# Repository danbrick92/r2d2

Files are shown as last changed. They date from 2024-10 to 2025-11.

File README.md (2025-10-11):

# R2D2
Create yourself an R2D2 robot! 

# Description
This robot, assuming all the electronic components are added, will have the ability to not only be remotely controlled, but has imaging, sound, and autonomous navigation. 

# Current State
Currently, this project is very much a WIP! I will update the README with a working YouTube video to showcase it's ability as a I go.

# Getting Started
There is a lot to setup with this. Considering this project includes electronics, 3d printing, robotics, software engineering, AI and more, this is both an expensive and complex project. 

## Essentials
To get started, you will need:
 - A 3d printer w/ plenty of filament
 - A soldering iron
 - Good working knowledge of: 
    - Electronics
    - 3d Printing
    - Linux
    - Docker
    - Robotics Operating System 2 (ROS2)
    - Python
    - C++
    - Machine Learning and AI

## Parts
You will need the following parts to mimic this design exactly. It is not cheap. 

### Computing Core
1) Raspberry Pi 5 8GB: https://www.canakit.com/raspberry-pi-5-8gb.html 
2) Raspberry Pi AI Kit with Extended Turbine Case, Fan, and Mega Heat Sink: https://www.canakit.com/raspberry-pi-ai-kit-with-case.html
    - You can also order these parts separate. 
    - The AI Kit is a Hailo 8L accelerator with up to 13 TOPS (Trillions of Operations Per Second) inferencing performance.
3) 512 GB MicroSD Card: https://www.amazon.com/dp/B09X7C2GBC
4) Arduino Uno: https://www.amazon.com/AEDIKO-Motor-Gearbox-Shaft-200RPM/dp/B099Z85573/ 

### Movement
1) TT Motor DC 3-6V Gearbox Motor Dual Shaft: https://www.amazon.com/AEDIKO-Motor-Gearbox-Shaft-200RPM/dp/B099Z85573/
2) Caster Wheels: https://www.amazon.com/dp/B0CZ9GNXSQ
3) Accelerometer/Gyroscope: https://www.amazon.com/dp/B00LP25V1A

### Power
1) 12V 5200mAh Battery: https://www.amazon.com/dp/B0C242DYT1
2) DC 9V 12V 24V to DC 5V 5A Buck Converter Module: https://www.amazon.com/UCTRONICS-Converter-Transformer-Voltage-Regulator/dp/B07XXWQ49N 
3) A USB C to USB A Cable: https://www.amazon.com/dp/B07DD5YHMH 
4) 22 awg Wires: https://www.amazon.com/dp/B07TX6BX47
5) Wire Strippers: https://www.amazon.com/dp/B073YG65N2  

### Imaging
1) USB Camera: https://www.amazon.com/Ximimark-Camera-Raspberry-Require-Drivers/dp/B07GWP2SGV/
2) LIDAR (TF Luna): https://www.amazon.com/gp/product/B088NVX2L7
3) LIDAR Cables: https://www.amazon.com/dp/B07PWZTC88 

## 3-D Prints

### R2D2

There are many good base models online. I found one (located in the credits section) and modified it to fit all the electronic components and screw together nicely.

I used white PETG for the feet, and white PLA for all other components. For the head and other details, I used 220 grit sandpaper and the following paints:
- Silver: Rust-Oleum Universal Titanium Silver Metallic
- Blue: Rust-Oleum Metallic Brilliant Metal Finish (Cobalt Blue)
- Gloss/Sealant: Rust-Oleum Gloss Clear Enamel

### Test Board

For me, it was helpful to have an easy test board before proceeding with the design of R2D2.

I created a circular plastic body with M3-sized holes and two expansion shafts to support multiple layers. For each layer, print:
- (1) roundBody 
- (2-3) shaftExpansion

On the top layer, you can print 
- (1) cameraLidarHolder, which allows the lidar and camera to mount to the top plate

You can also print cubeHolders as needed to secure your boards/equipment

You can access the stl prints in print/test/
I purchased these M3 screws from Amazon: https://www.amazon.com/dp/B0BMQFHDBH

This 3D print was very helpful to mount the motors to the bottom of the board: https://www.thingiverse.com/thing:1473508 

## Electronics
Here is the breadboard design for setting up this system:
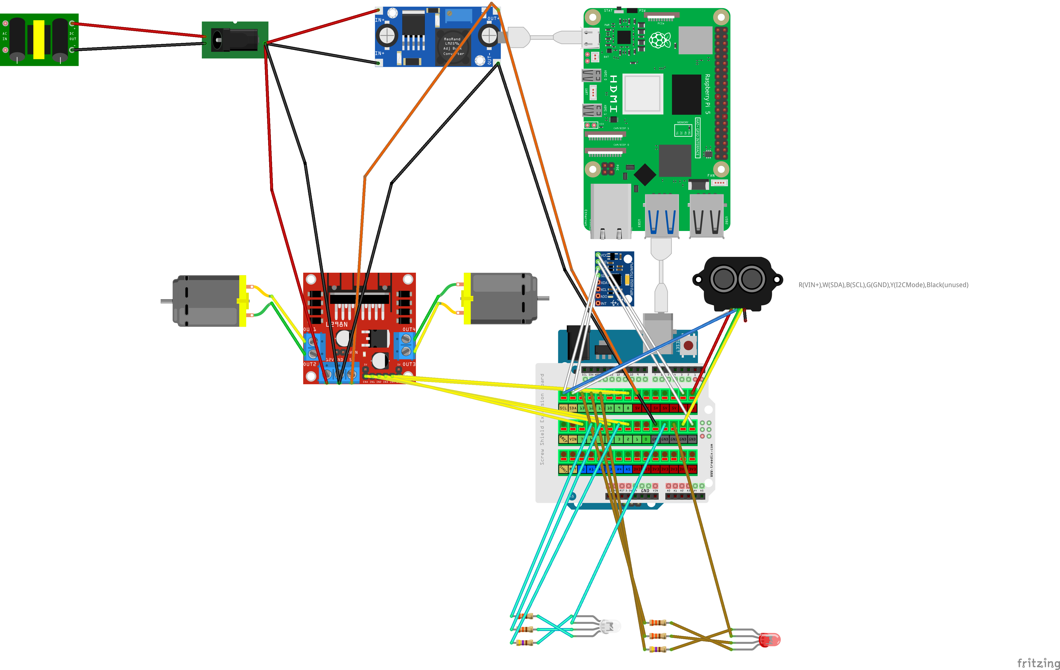
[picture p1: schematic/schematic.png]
The schematic
 

I've left the Fritzing project here and the subparts used in case anyone wants to alter the design.

# Installation
NOTE THAT THIS IS STILL VERY MUCH A WIP. 
1) Load up your Raspberry PI 5 with a 64-bit installation of Raspberry PI. The version I used was Raspberry PI OS 12.7 64-bit.
2) Once the PI is booted and ready, copy the contents of this repo into a directory you prefer.
3) Open a terminal up and cd to the src directory. 
4) Run ```sudo pi/install.sh``` - this will install Docker, ROS, and a number of other dependencies
5) Finally, you should be able to run ```sudo run.sh``` - this will run the robotics engine

# Running It
TBD

# Credits
## 3-D Printed Parts

### r2d2
This project is a remix of the R2D2 Alexa Echo Dot 3 Dock created by Gerrylum, licensed under CC BY-NC 4.0: https://www.printables.com/model/35415-screen-accurate-r2d2-alexa-echo-dot-3-dock

I modified the original design by scaling it up, making accomodations for electronic components, and screw holes.

Additional body detail parts were sourced from this remix.

### motorMount
Motor mount by b2vn on Thingiverse: https://www.thingiverse.com/thing:1473508
This 3D model was created by b2vn on Thingiverse and is licensed under the Creative Commons Attribution-ShareAlike (CC BY-SA) license.

### 28BYJ-48 Motor Welle Shaft Crankshaft Extension
https://www.thingiverse.com/thing:6189216/files

### 28BYJ-48 Mounting Bracket
https://www.thingiverse.com/thing:423357/files

## Sounds
Sounds downloaded from: https://www.101soundboards.com/boards/10634-r2-d2-sounds-star-wars

## Fritzing Parts
### bb-usb-cable
This part was created by vanepp on the Fritzing Forum.
The part is shared for public use as part of the open-source Fritzing community.
Original Source: https://forum.fritzing.org/t/usb-cable-in-breadboard-view/11697

### dc_motor_devre
This part was created by bminaa on the Fritzing website.
The part is shared for public use as part of the open-source Fritzing community.
Original Source: https://fritzing.org/projects/dc-motor

### generic-ac-power-supply
This part was created by vanepp on the Fritzing Forum.
The part is shared for public use as part of the open-source Fritzing community.
Original Source: https://forum.fritzing.org/t/i-need-a-power-supply/8471

### L298N DC motor driver
This part was created by codefls on the Fritzing Forum.
The part is shared for public use as part of the open-source Fritzing community.
Original Source: https://forum.fritzing.org/t/h-bridge-with-l298n-motor-driver/7711 

### MPU-6050 Board GY-521
This part was created by charlesrct on the Fritzing Website.
The part is shared for public use as part of the open-source Fritzing community.
Original Source: https://fritzing.org/projects/mpu-6050-board-gy-521-acelerometro-y-giroscopio 

### Raspberry-Pi5
This part was created by vanepp on the Fritzing Forum.
The part is shared for public use as part of the open-source Fritzing community.
Original Source: https://forum.fritzing.org/t/looking-for-raspberry-pi-5-fritzing-part/21511

### tfluna-lidar
This part was created by vanepp on the Fritzing Forum.
The part is shared for public use as part of the open-source Fritzing community.
Original Source: https://forum.fritzing.org/t/tf-luna-8m-low-cost-distance-sensor/16499

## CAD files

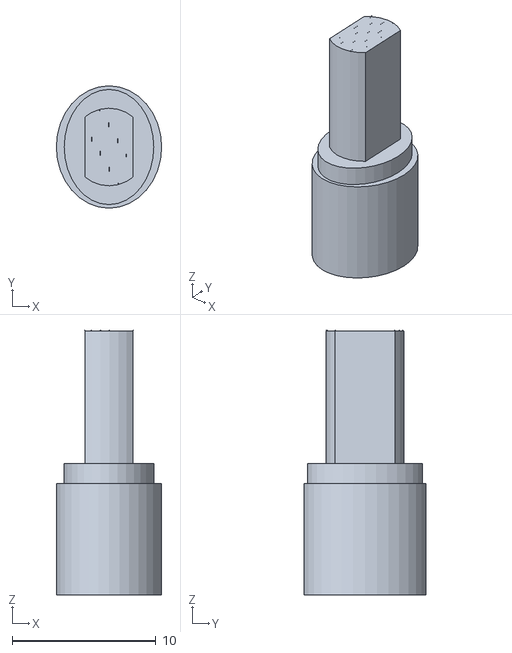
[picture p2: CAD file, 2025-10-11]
print/real/ref/28byj-48-MotorwelleShaft_ungefahr.stl
7.34 x 8.52 x 18.5

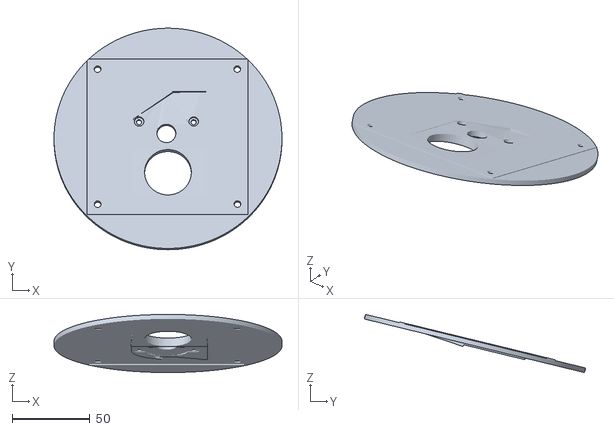
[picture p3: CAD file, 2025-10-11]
print/real/v1/body_susan_mount.stl
146.3 x 142.1 x 37.3

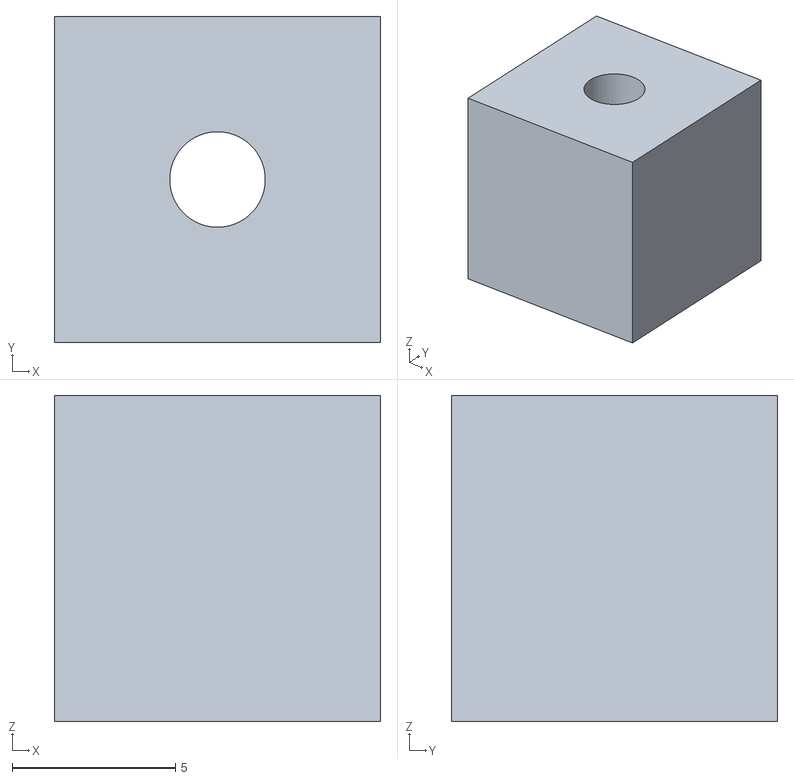
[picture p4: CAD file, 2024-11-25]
print/test/cubeHolder.stl
10.0 x 10.0 x 10.0

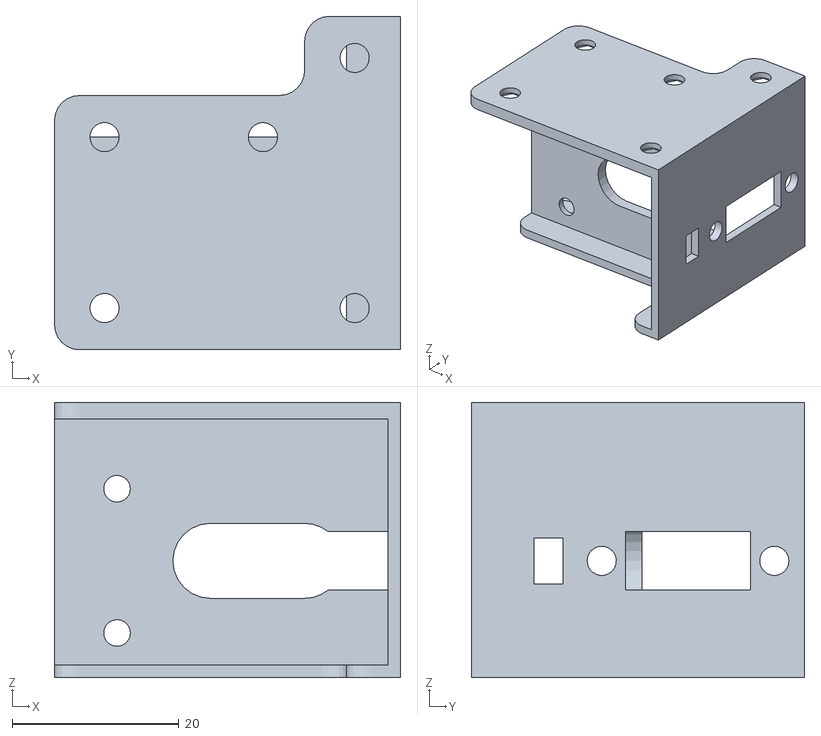
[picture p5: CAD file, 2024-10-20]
print/test/motorMount/files/motorMount.stl
41.5 x 40.0 x 33.0

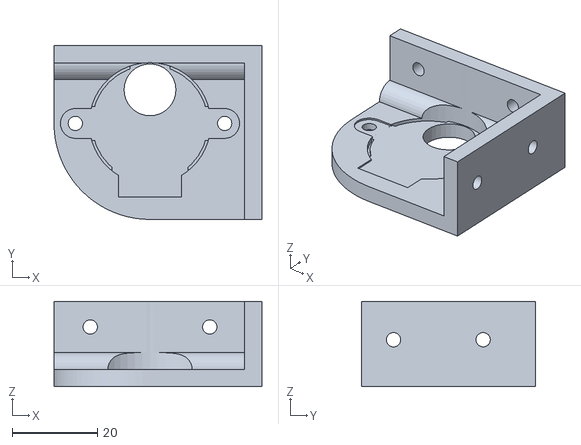
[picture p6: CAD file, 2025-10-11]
print/real/ref/Bracket_28BYJ-48_v3.stl
48.8 x 40.8 x 20.0

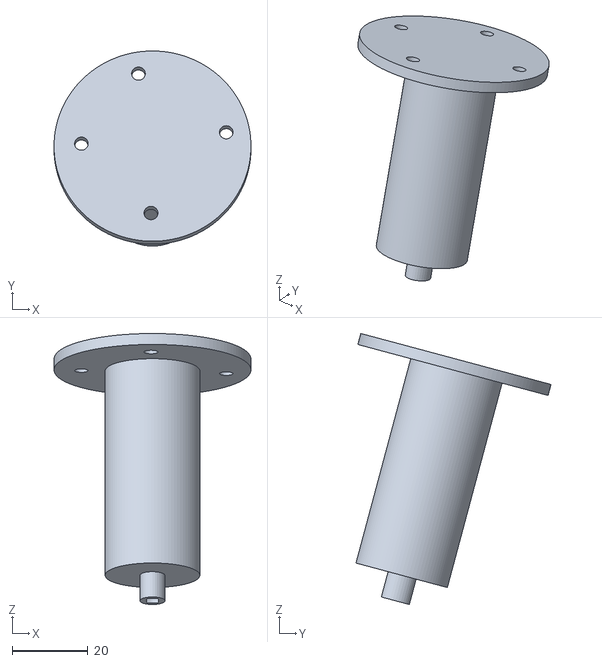
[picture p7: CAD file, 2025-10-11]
print/real/v1/motor_shaft.stl
52.0 x 51.5 x 71.5

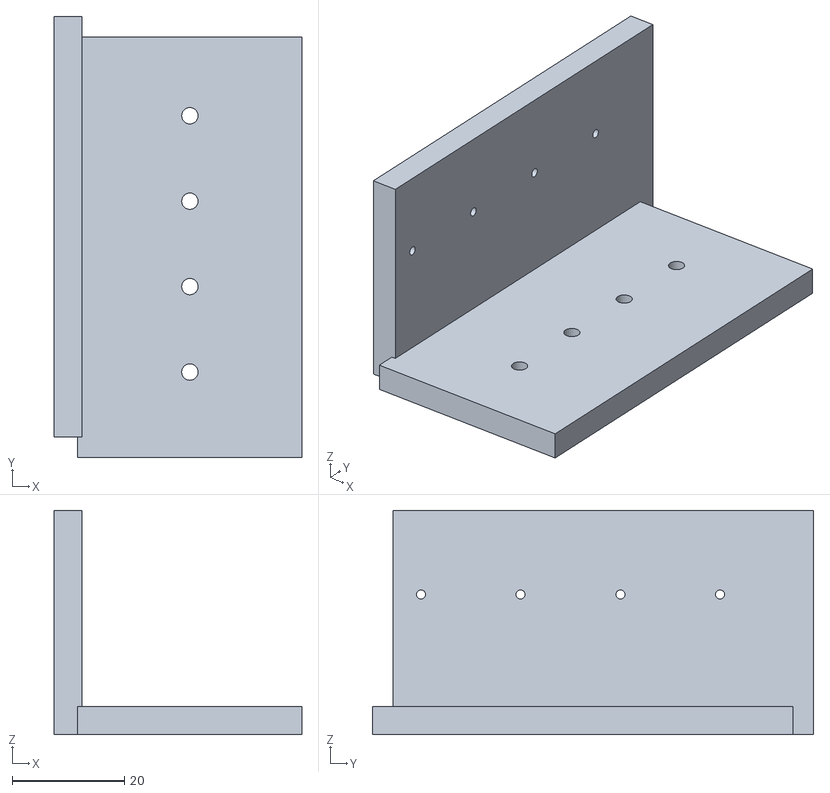
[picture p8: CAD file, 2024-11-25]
print/test/cameraLidarHolder.stl
44.2 x 78.7 x 40.0

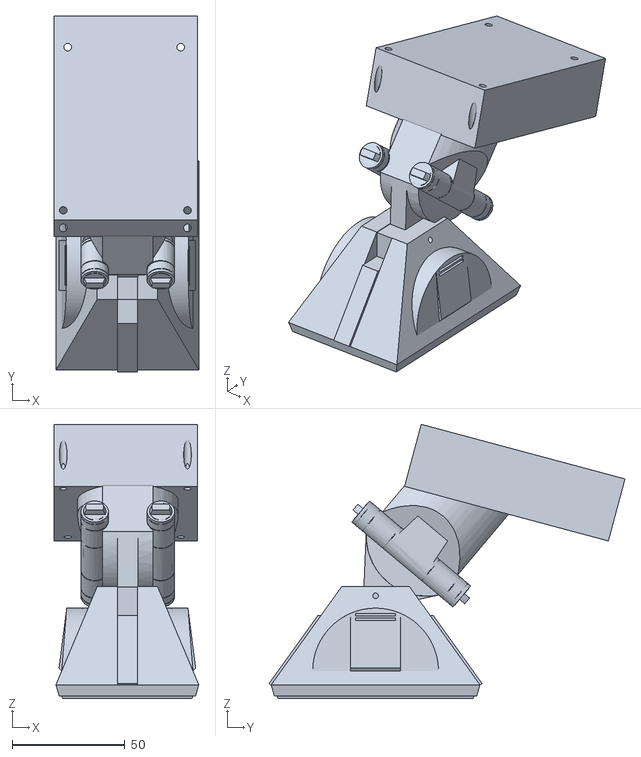
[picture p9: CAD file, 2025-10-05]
print/real/v1/center_leg.stl
64.0 x 157.6 x 121.4

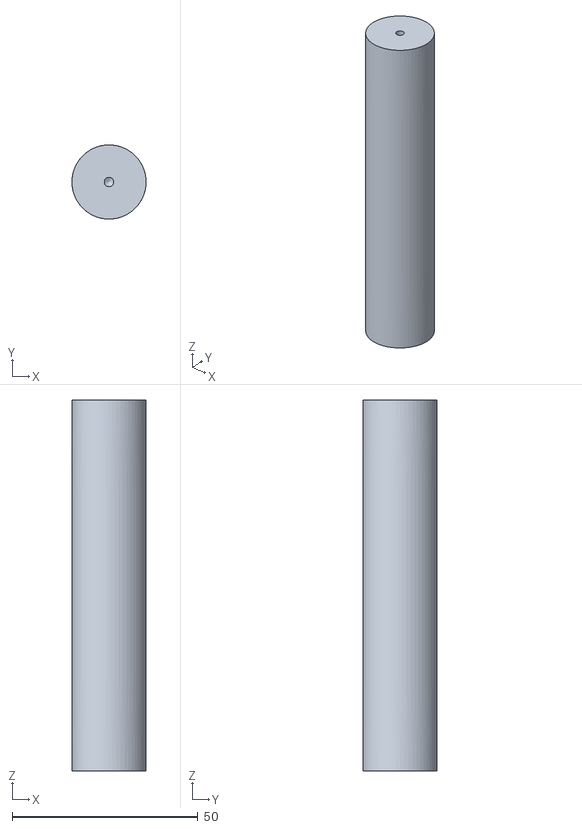
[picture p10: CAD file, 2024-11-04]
print/test/shaftExpansion.stl
20.0 x 20.0 x 100.0

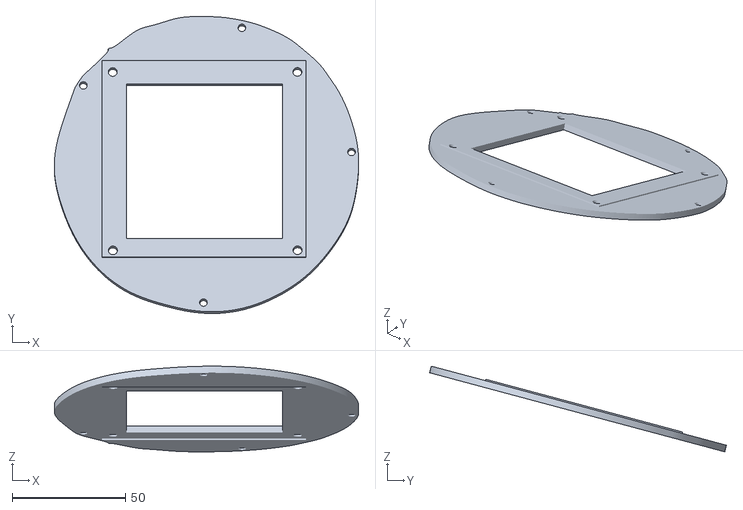
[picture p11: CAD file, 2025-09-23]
print/real/v1/lazy_susan_head.stl
134.4 x 131.1 x 37.8

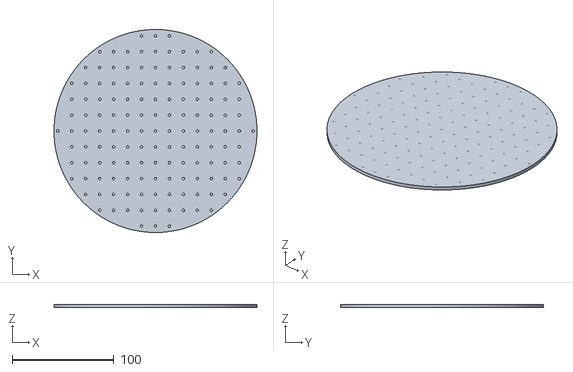
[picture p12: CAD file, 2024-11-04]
print/test/roundBody.stl
200.0 x 200.0 x 3.00

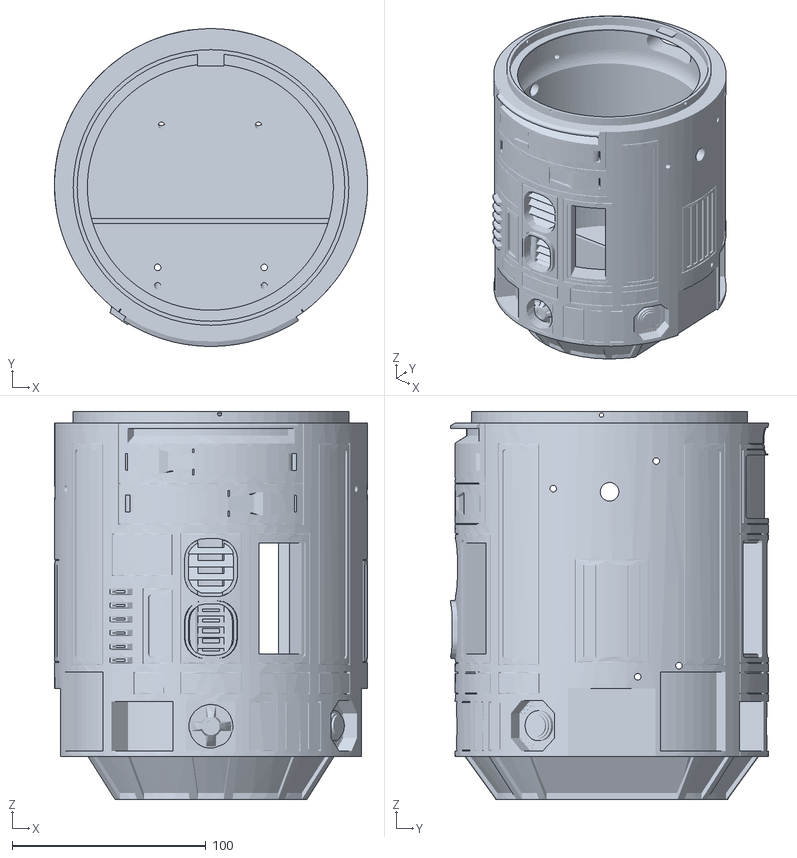
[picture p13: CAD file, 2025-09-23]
print/real/v1/body.stl
161.5 x 163.9 x 200.1

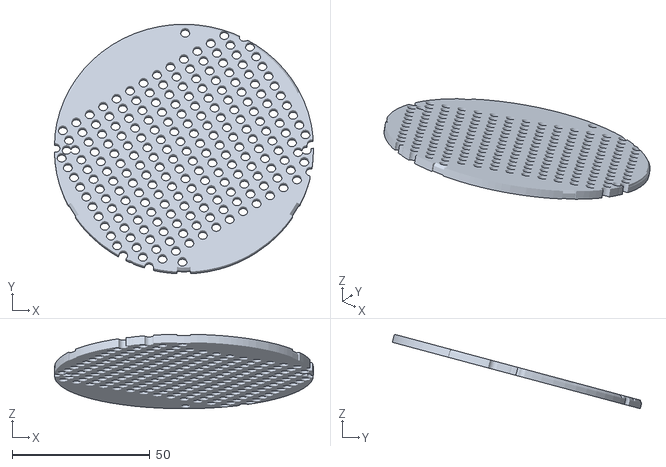
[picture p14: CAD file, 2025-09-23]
print/real/v1/head_ceiling_plate.stl
93.9 x 90.5 x 27.0

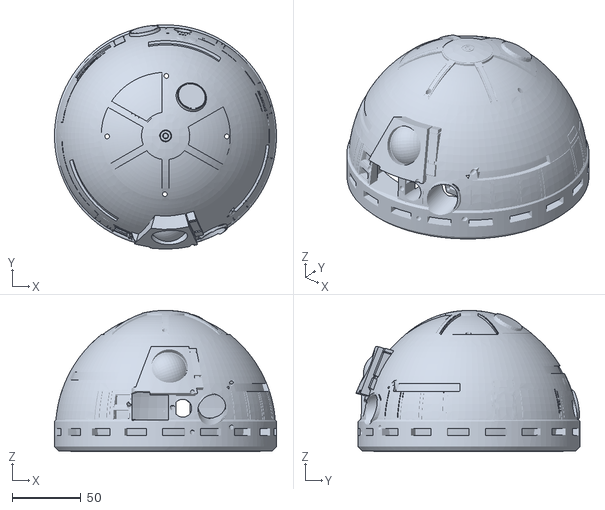
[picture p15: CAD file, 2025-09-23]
print/real/v1/head.stl
161.5 x 163.1 x 102.7

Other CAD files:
print/test/motorMount/files/motorMountMirrored.stl
print/real/v1/lazy_susan_body.stl
print/real/v1/left_foot.stl
print/real/v1/right_foot.stl
print/real/v1/left_leg.stl
print/real/v1/right_leg.stl

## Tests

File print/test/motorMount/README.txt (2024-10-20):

Motor mount by b2vn on Thingiverse: https://www.thingiverse.com/thing:1473508

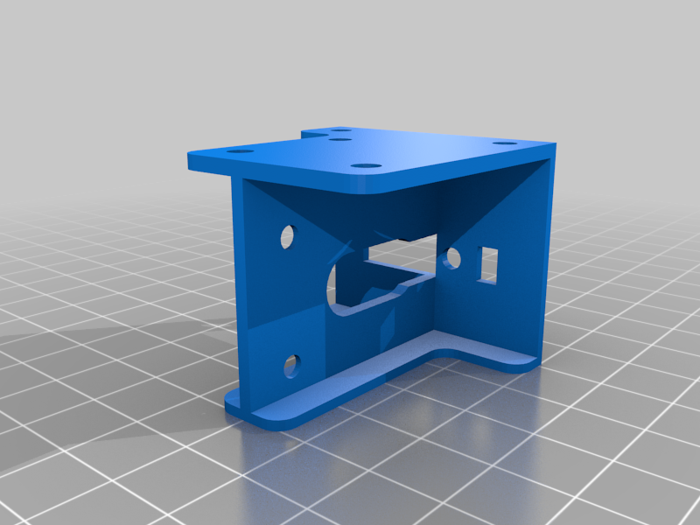
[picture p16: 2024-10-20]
print/test/motorMount/images/3c52334d17b0fe4ae1f2c2ae52ba4748.png

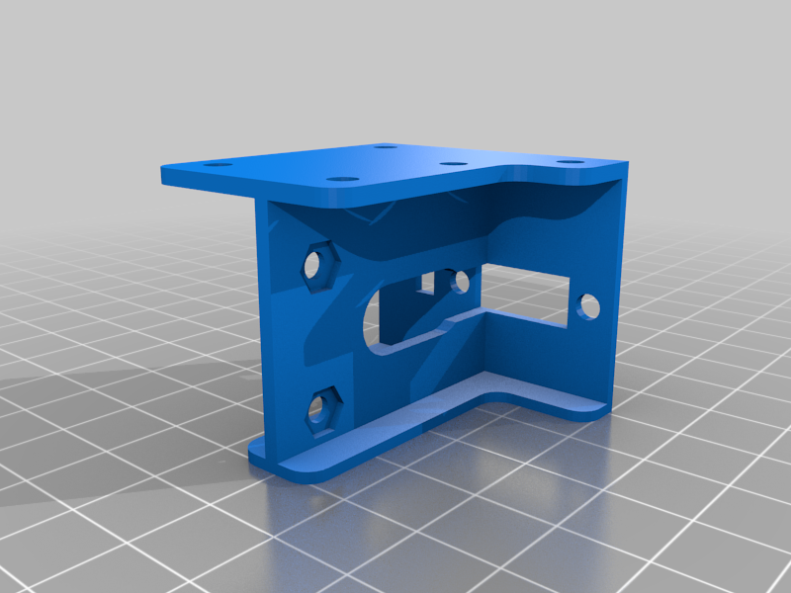
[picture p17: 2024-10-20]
print/test/motorMount/images/56ac4bdb9e9e2a24071e5319d71b0ec3.png

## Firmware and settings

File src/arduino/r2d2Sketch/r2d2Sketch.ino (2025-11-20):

/*
  This sketch performs the following functions
  - Reads LIDAR data from the TF Luna sensor
  - Reads Accelerometer & Gyro data from HW-123
  - Read and Write multi-color leds
  - Allows for control of wheels (motors)
  - Control stepper motors

  The code is setup minimally, to allow the Pi full control
  This includes calibration

  **NOTE: Make sure to install TFLI2C.h library **

  Author: Dan Brickner
*/
// (motors,set,magnitude=200,direction=96)

#include <Stepper.h>
#include "Wire.h"
#include "TFLI2C.h"

// Common Settings
const bool SHOULD_PRINT = true;
const unsigned long SERIAL_BAUD = 38400;

// Front LED Settings
const int FRONT_LED_R_PIN = 3;
const int FRONT_LED_G_PIN = 6;
const int FRONT_LED_B_PIN = 5;

// Back LED Settings
const int BACK_LED_R_PIN = 11;
const int BACK_LED_G_PIN = 13;
const int BACK_LED_B_PIN = 12;

// TFLuna Settings
const byte TFLUNA_ADDRESS = 0x10;
TFLI2C tfLunaSensor;

// HW123 Settings
const byte HW123_ADDRESS = 0x68;

// Motor Settings
const int MOTOR_LEFT_FORW_PIN = 4;
const int MOTOR_LEFT_BACK_PIN = 2;
const int MOTOR_LEFT_SPEED_PIN = 10;
const int MOTOR_RIGHT_FORW_PIN = 8;
const int MOTOR_RIGHT_BACK_PIN = 7;
const int MOTOR_RIGHT_SPEED_PIN = 9;
int MOTOR_MIN_SPEED_LEFT = 0;
int MOTOR_MIN_SPEED_RIGHT = 0;

// Stepper
#define STEPS_PER_REV 2048   // 28BYJ-48 has ~2048 steps per full rotation
Stepper myStepper(STEPS_PER_REV, A0, A2, A1, A3);
// note the slightly odd order: (IN1, IN3, IN2, IN4) for correct sequence


// Data Structures
struct ledState {
  int red;
  int green;
  int blue;
};
struct tfLunaState {
  int16_t distance;
  int16_t strength;
  int16_t temperature;
  bool success;
};
struct hw123State {
  int16_t accelX;
  int16_t accelY;
  int16_t accelZ;
  int16_t gyroX;
  int16_t gyroY;
  int16_t gyroZ;
  int16_t temp;
};
struct motorState {
  bool forward;
  bool backward;
  int leftSpeed;
  int rightSpeed;
};
struct stepperState {
  int rpm_speed;
  int current_step;
};


// Current States
struct ledState FRONT_LED_STATE = {0, 0, 0};
struct ledState BACK_LED_STATE = {0, 0, 0};
struct tfLunaState TFLUNA_STATE = {0, 0, 0, false};
struct hw123State HW123_STATE = {0, 0, 0, 0, 0, 0, 0};
struct motorState MOTOR_STATE = {false, false, 0, 0};
struct stepperState STEPPER_STATE = {10, 0};

//----------------------------------
// Common
//----------------------------------
void setup(){
  Serial.begin(SERIAL_BAUD);
  Wire.begin();

  initFrontLED();
  initBackLED();
  // no intialization needed for TFLuna
  inithw123();
  initMotors();
  initStepperMotor();
}

void loop() {
  // Check for incoming commands
  while (Serial.available() > 0) {
    String line = Serial.readStringUntil('\n');
    if (line.length() > 0) {
      routeCommand(line);
    }
    yield();
  }

  // Send sensor data
  static unsigned long lastSend = 0;
  if (millis() - lastSend > 50) {  // every 50 ms = 20 Hz
    frontLEDRead();
    backLEDRead();
    tfLunaRead();
    hw123Read();
    motorStateRead();
    stepperMotorRead();
  }
}

void routeCommand(String line){
  // Send command to the correct function
  line.trim();

  char device = line.charAt(0);
  char event = line.charAt(1);
  String data = line.substring(2);

  if (device == 'f' && event == 'w'){  // front led write
    frontLEDWrite(data);
  }
  else if (device == 'b' && event == 'w'){  // back led write
    backLEDWrite(data);
  }
  else if (device == 'm' && event == 'w'){  // wheel motor write
    motorWrite(data);
  }
  else if (device == 's' && event == 'w'){  // head stepper motor write
    stepperMotorWrite(data);
  }
}

void writeSerialLine(String device, String event, String data){
  // Streamlined interface for writing to serial
  Serial.print(device);
  Serial.print(event);
  Serial.println(data);
}

// ---------------------------------
// Front LED
// ---------------------------------
void initFrontLED(){
  // Initialize
  pinMode(FRONT_LED_R_PIN, OUTPUT);
  pinMode(FRONT_LED_G_PIN, OUTPUT);
  pinMode(FRONT_LED_B_PIN, OUTPUT);
  struct ledState newState = {0, 0, 0};
  frontLEDSetColor(newState);
}

void frontLEDSetColor(struct ledState colors) {
  analogWrite(FRONT_LED_R_PIN, colors.red);
  analogWrite(FRONT_LED_G_PIN, colors.green);
  analogWrite(FRONT_LED_B_PIN, colors.blue);
  FRONT_LED_STATE = {colors.red, colors.green, colors.blue};
}

void frontLEDWrite(String data){
  // Parse data points
  data.trim();
  struct ledState newState = {0, 0, 0};

  // Temporary variables
  int r = 0, g = 0, b = 0;

  // Use sscanf to parse three integers separated by spaces
  if (sscanf(data.c_str(), "%d %d %d", &r, &g, &b) == 3) {
    // Clamp values to 0-255 just in case
    newState.red = constrain(r, 0, 255);
    newState.green = constrain(g, 0, 255);
    newState.blue = constrain(b, 0, 255);
    frontLEDSetColor(newState);
  } else {
    String errorMsg = "Invalid LED command: " + data;
    writeSerialLine("f", "e", errorMsg);
  }
}

void frontLEDRead(){
  writeSerialLine("f", "r", String(FRONT_LED_STATE.red) + " " + String(FRONT_LED_STATE.green) + " " + String(FRONT_LED_STATE.blue));
}

// ---------------------------------
// Back LED
// ---------------------------------
void initBackLED(){
  pinMode(BACK_LED_R_PIN, OUTPUT);
  pinMode(BACK_LED_G_PIN, OUTPUT);
  pinMode(BACK_LED_B_PIN, OUTPUT);
  struct ledState newState = {0, 0, 0};
  backLEDSetColor(newState);
}

void backLEDSetColor(struct ledState colors) {
  analogWrite(BACK_LED_R_PIN, colors.red);
  analogWrite(BACK_LED_G_PIN, colors.green);
  analogWrite(BACK_LED_B_PIN, colors.blue);
  BACK_LED_STATE = {colors.red, colors.green, colors.blue};
}

void backLEDWrite(String data){
  // Parse data points
  data.trim();
  struct ledState newState = {0, 0, 0};

  // Temporary variables
  int r = 0, g = 0, b = 0;

  // Use sscanf to parse three integers separated by spaces
  if (sscanf(data.c_str(), "%d %d %d", &r, &g, &b) == 3) {
    // Clamp values to 0-255 just in case
    newState.red = constrain(r, 0, 255);
    newState.green = constrain(g, 0, 255);
    newState.blue = constrain(b, 0, 255);

    // This LED is binary - 0 or 255
    if (newState.red < 128){
      newState.red = 0;
    }
    else {
      newState.red = 255;
    }
    if (newState.green < 128){
      newState.green = 0;
    }
    else {
      newState.green = 255;
    }
    if (newState.blue < 128){
      newState.blue = 0;
    }
    else {
      newState.blue = 255;
    }

    backLEDSetColor(newState);
  } else {
    String errorMsg = "Invalid LED command: " + data;
    writeSerialLine("f", "e", errorMsg);
  }
}

void backLEDRead(){
  writeSerialLine("b", "r", String(BACK_LED_STATE.red) + " " + String(BACK_LED_STATE.green) + " " + String(BACK_LED_STATE.blue));
}

//----------------------------------
// TF Luna
//----------------------------------
void tfLunaRead(){
  // Initiate variables
  int16_t distance;
  int16_t strength;
  int16_t temperature; 
  bool success;

  // Get data from sensor
  success = tfLunaSensor.getData(distance, strength, temperature, TFLUNA_ADDRESS);
  TFLUNA_STATE = {distance, strength, temperature, success};
  if (success) {
    writeSerialLine("t", "r", String(distance) + " " + String(strength) + " " + String(temperature));
  }
  else {
    // Have to do custom print due to API
    Serial.print("te");
    tfLunaSensor.printStatus(); // Print error status
    Serial.println("");
  }
}

//----------------------------------
// HW-123 (Accel/Gyro)
//----------------------------------
void inithw123() {
  Wire.beginTransmission(HW123_ADDRESS);
  Wire.write(0x6B); // Power management register
  Wire.write(0x00); // Wake up the sensor
  Wire.endTransmission();
}

void hw123Read(){
  int16_t accelX;
  int16_t accelY;
  int16_t accelZ;
  int16_t temp;
  int16_t gyroX;
  int16_t gyroY;
  int16_t gyroZ;

  Wire.beginTransmission(HW123_ADDRESS);
  Wire.write(0x3B); // Starting register for accelerometer data
  Wire.endTransmission(false); // Keep I2C connection open
  Wire.requestFrom((uint8_t)HW123_ADDRESS, (uint8_t)14); // Request 14 bytes: Accel(6), Temp(2), Gyro(6)

  if (Wire.available() == 14) {
    // Read accelerometer data
    accelX = (Wire.read() << 8) | Wire.read();
    accelY = (Wire.read() << 8) | Wire.read();
    accelZ = (Wire.read() << 8) | Wire.read();

    // Read temperature data
    temp = (Wire.read() << 8 | Wire.read()); // Temp High, Low

    // Read gyroscope data
    gyroX = (Wire.read() << 8) | Wire.read();
    gyroY = (Wire.read() << 8) | Wire.read();
    gyroZ = (Wire.read() << 8) | Wire.read();
  }

  HW123_STATE = {accelX, accelY, accelZ, gyroX, gyroY, gyroZ, temp};

  // Print
  writeSerialLine("h", "r", String(accelX) + " " + String(accelY) + " " + String(accelZ) + " " + String(gyroX) + " " + String(gyroY) + " " + String(gyroZ) + " " + String(temp));
}

//----------------------------------
// Motors
//----------------------------------
void initMotors() {
  pinMode(MOTOR_LEFT_FORW_PIN, OUTPUT);
  pinMode(MOTOR_LEFT_BACK_PIN, OUTPUT);
  pinMode(MOTOR_LEFT_SPEED_PIN, OUTPUT);
  pinMode(MOTOR_RIGHT_FORW_PIN, OUTPUT);
  pinMode(MOTOR_RIGHT_BACK_PIN, OUTPUT);
  pinMode(MOTOR_RIGHT_SPEED_PIN, OUTPUT);
}

void motorWrite(String data){
  data.trim();
  struct motorState newState = {false, false, 0, 0};

  // Temporary variables
  int f = 0, b = 0, ls = 0, rs = 0;

  // Use sscanf to parse three integers separated by spaces
  if (sscanf(data.c_str(), "%d %d %d %d", &f, &b, &ls, &rs) == 4) {
    // Assign and constrain
    newState.forward = (f != 0);
    newState.backward = (b != 0);
    newState.leftSpeed = constrain(ls, 0, 250);
    newState.rightSpeed = constrain(rs, 0, 250);

    // Ensure bad states aren't possible
    if (newState.forward && newState.backward){
      newState.forward = false;
      newState.backward = false;
    }

    // Write to pins
    digitalWrite(MOTOR_LEFT_FORW_PIN, newState.forward);
    digitalWrite(MOTOR_LEFT_BACK_PIN, newState.backward);
    analogWrite(MOTOR_LEFT_SPEED_PIN, newState.leftSpeed);
    digitalWrite(MOTOR_RIGHT_FORW_PIN, newState.forward);
    digitalWrite(MOTOR_RIGHT_BACK_PIN, newState.backward);
    analogWrite(MOTOR_RIGHT_SPEED_PIN, newState.rightSpeed);

    // Update State
    MOTOR_STATE = newState;
  }
  else {
    String errorMsg = "Invalid Motor command: " + data;
    writeSerialLine("m", "e", errorMsg);
  }
}

void motorStateRead(){
  writeSerialLine("m", "r", String(MOTOR_STATE.forward) + " " + String(MOTOR_STATE.backward) + " " + String(MOTOR_STATE.leftSpeed) + " " + String(MOTOR_STATE.rightSpeed));
}

//----------------------------------
// Head Stepper Motor
//----------------------------------
void initStepperMotor() {
  myStepper.setSpeed(10);
}

void stepperMotorRead(){
    writeSerialLine("s", "r", String(STEPPER_STATE.rpm_speed) + " " + String(STEPPER_STATE.current_step));
}

void stepperMotorWrite(String data){
    data.trim();
    struct stepperState newState = {0, 0};

    // Temporary variables
    int speed = 0, steps = 0;

    // Use sscanf to parse three integers separated by spaces
    if (sscanf(data.c_str(), "%d %d", &speed, &steps) == 2) {
      newState.rpm_speed = constrain(speed, 0, 20);  // clamp to a safe RPM range
      newState.current_step = constrain(steps, -100, 100);

      myStepper.setSpeed(newState.rpm_speed);
      // Move the motor (blocking call)
      if (newState.current_step != 0 && newState.rpm_speed > 0) {
        myStepper.step(newState.current_step);
      }
    }
    else {
      String errorMsg = "Invalid Stepper command: " + data;
      writeSerialLine("s", "e", errorMsg);
    }
}

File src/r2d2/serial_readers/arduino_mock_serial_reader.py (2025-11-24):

import asyncio
import time
from copy import deepcopy
from typing import Dict

from r2d2.serial_readers.base_serial_reader import BaseSerialReader
from r2d2.utils.context import Context


class ArduinoMockSerialReader(BaseSerialReader):

    def __init__(self, context: Context) -> None:
        super().__init__(context)
        self.rate = self.config.arduino_mock_serial_reader.rate
        self.queue: Dict[float, str] = {}

    async def start(self) -> None:
        while True:
            current_time = time.time()
            data = self.__mock_read()
            self.queue[current_time] = data
            await asyncio.sleep(self.rate)

    def __mock_frontled_read(self) -> str:
        return "fr100 100 100\n"

    def __mock_backled_read(self) -> str:
        return "br0 0 255\n"

    def __mock_tfluna_read(self) -> str:
        return "tr393 1122 4900\n"

    def __mock_hw123_read(self) -> str:
        return "hr1488 -16264 3056 -32 182 83 -4464\n"

    def __mock_motor_read(self) -> str:
        return "mr0 0 0 0\n"

    def __mock_stepper_read(self) -> str:
        return "sr10 0\n"

    def __mock_read(self) -> str:
        serial = ""
        serial += self.__mock_frontled_read()
        serial += self.__mock_backled_read()
        serial += self.__mock_tfluna_read()
        serial += self.__mock_hw123_read()
        serial += self.__mock_motor_read()
        serial += self.__mock_stepper_read()
        return serial

    async def read_serial(self) -> str:
        data = ""
        queue = deepcopy(self.queue)
        for k, v in queue.items():
            data += v
            del self.queue[k]
        return data

    async def catchup(self) -> None:
        self.log(message="Catching up by clearing queue")
        self.queue = {}

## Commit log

2024-11-25 Adding schematic
    [cameraLidarHolder.stl, cubeHolder.stl, dc_motor_devre.fzz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]
2024-12-01 Setting motors
2024-12-01 Fix wheel driver
2024-12-01 Update schematic
    [schematic.fzz]
2024-12-10 Adding credit
    [testBoardschematic.fzz]
2025-09-19 Adding r2d2 print files
    [body.stl, center_leg.stl, head.stl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]
2025-09-23 R2D2 updates
    [body.stl, center_leg (1).stl, head.stl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]
2025-10-11 updating schematics
    [28byj-48-MotorwelleShaft_ungefahr.stl, Bracket_28BYJ-48_v3.stl, body_susan_mount.stl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]
2025-10-20 Efficiency arduino
    [schematic.fzz]
2025-10-20 Update LEDs
2025-10-23 Correct motor issues
